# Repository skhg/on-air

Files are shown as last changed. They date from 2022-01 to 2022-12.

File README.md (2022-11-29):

# on-air

I wanted an "On Air" sign that would show up behind me while I'm in a video call at work.

Since I work from home in the living room, this is a useful indicator to my wife that I'm in a meeting (even if muted and just listening). It's also something fun that shows up behind me while in a call and gets many nice compliments!

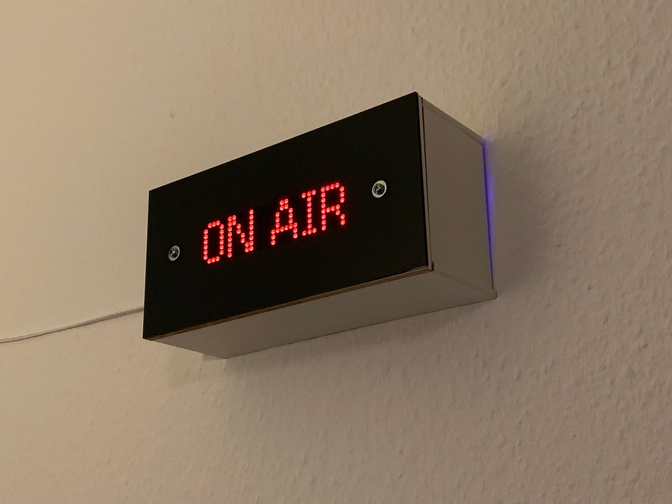
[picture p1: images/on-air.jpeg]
On air sign On Air sign


# Goals for the project
 * "On Air" status must be triggered automatically when Zoom calls begin or end
 * Learn some basic woodworking skills
 * Make the finished product look minimal and stylish
 * Learn how to use an RTC (Real-time clock) module
 * Include multiple modes so the project can be interacted with

## Materials required
Electronics:
* [NodeMCU v3 ESP8266](https://www.amazon.de/-/en/gp/product/B074Q2WM1Y/ref=ppx_yo_dt_b_search_asin_title?ie=UTF8&psc=1) microcontroller board
* 8x32 [LED matrix](https://www.amazon.de/-/en/gp/product/B079HVW652/ref=ppx_yo_dt_b_search_asin_title?ie=UTF8&psc=1)
* DS3231 [Real-time clock module](https://www.amazon.de/-/en/gp/product/B077XN4LL4/ref=ppx_yo_dt_b_search_asin_title?ie=UTF8&psc=1)
* Cables
* Breadboard
* A long [USB cable](https://www.amazon.de/-/en/gp/product/B01NCJHEHJ/ref=ppx_yo_dt_b_search_asin_title?ie=UTF8&psc=1)

Case:
* 3mm [darkened perspex / acrylic](https://www.amazon.de/-/en/gp/product/B0856148X9/ref=ppx_yo_dt_b_search_asin_title?ie=UTF8&psc=1)
* Nuts and bolts
* 6mm MDF board (sourced from leftover IKEA shelving)

Tools:
* Jigsaw
* [Clamps](https://www.amazon.de/gp/product/B0875RW1Y6/ref=ppx_yo_dt_b_asin_title_o02_s00?ie=UTF8&psc=1)
* [Wood glue](https://www.amazon.de/gp/product/B0012FBQ0U/ref=ppx_yo_dt_b_asin_title_o03_s00?ie=UTF8&psc=1)
* [Jigsaw table](https://www.amazon.de/gp/product/B0011KXNC0/ref=ppx_yo_dt_b_asin_title_o04_s00?ie=UTF8&psc=1)
* Drill

## Design, build and test
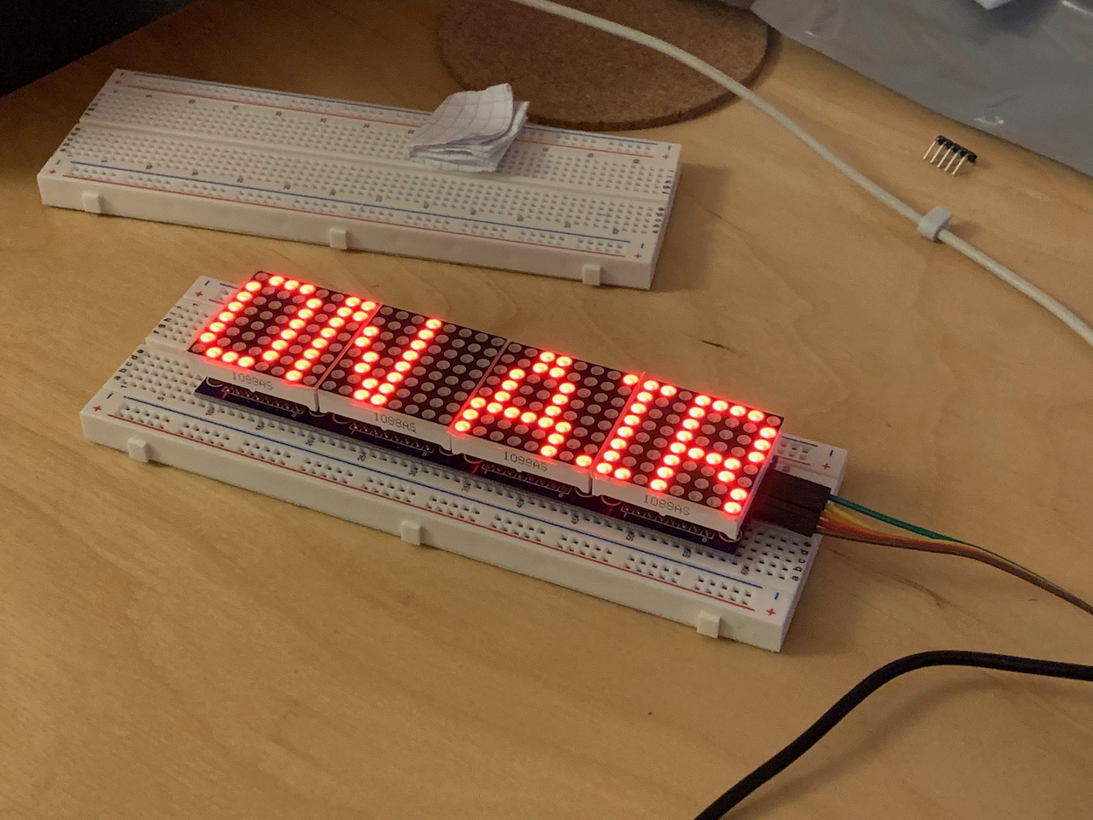
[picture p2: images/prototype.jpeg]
Prototyping the electronics came first, as usual. I hadn't worked with a large LED pixel array before, so this was the first thing I wanted to get right. With the `LedControl` library this is actually quite easy!

I was inspired by [this design](http://www.tjstephens.com/blog/2016/05/16/led-matrix-display/) which took an old wine box and converted it into an 8x64 LED display.

Beyond the cliché "ON AIR" message, I also wanted a couple of other modes to be available. As this is a wall piece that'll be visible from the whole room, a clock mode seemed obvious. That meant testing out the DS3231 RTC module. It turns out (!) that lots of DS3231 modules available online ship with a flaw that puts the battery at risk of overcharging and possible explosion. However, [desoldering a resistor](https://forum.arduino.cc/t/zs-042-ds3231-rtc-module/268862/70) will safely avoid this risk.

### Building the case
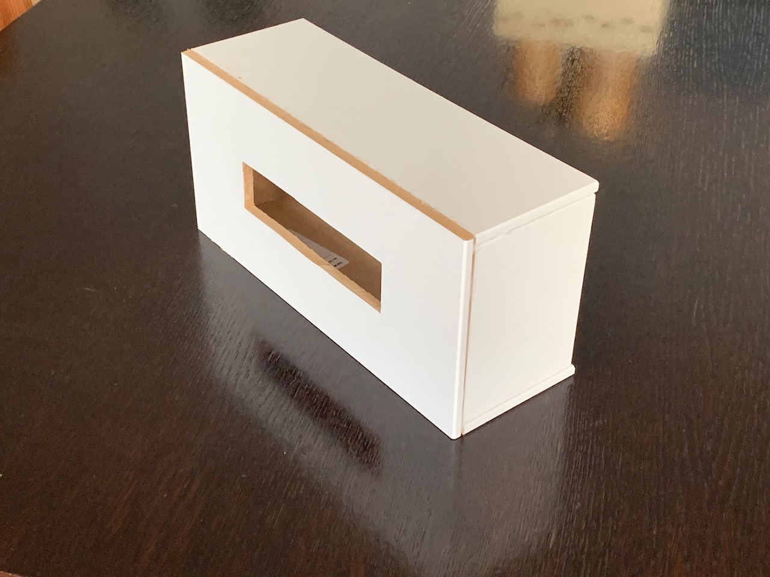
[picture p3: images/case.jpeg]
The case is made from pieces of 6mm MDF that were "upcycled" from leftover IKEA shelving. Each piece was measured and drawn out, then cut with a household jigsaw tool. Videos [like this](https://www.youtube.com/watch?v=jWneDzqAbH8) were really helpful for me to know how where to get started with it.

After cutting the pieces, and cutting out the front slot for the LED's, I applied wood glue and clamped the sides together. Some heavy weight from above helped to keep the sides stuck on to the front. I left the glue to cure for about 24 hours.

Next, I checked that the LED's fit correctly and snugly into the front slot. They did!

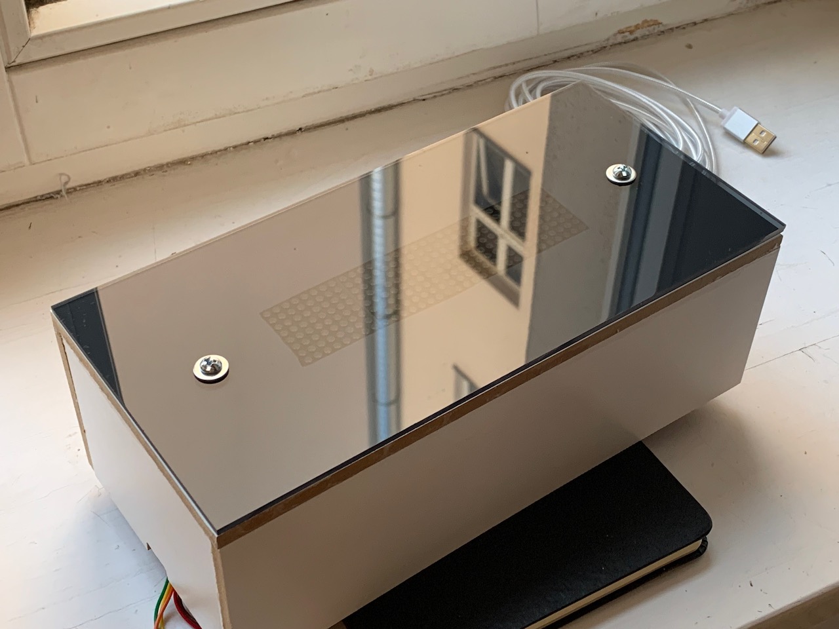
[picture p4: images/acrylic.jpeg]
The acrylic front cover came with protective plastic on both sides. Leaving this on, I carefully drilled through the acrylic to leave a clean cut on both sides. Separately I drilled through the front cover in the same location. After confirming the alignment, I removed the acrylic's protective cover and bolted it to the case, with some washers to distribute the force a little better. It's a snug fit but doesn't need to be too tight.

Final dimensions:
* 250mm wide
* 89mm deep (86mm case + 3mm acrylic)
* 120mm tall
* LED slot
  * 130mm wide
  * 32mm tall

### Circuit design

Everything is mounted on a breadboard and wired to that. There's plenty of space left inside the case - in fact it could be slimmer, if I was to build another version in the future.

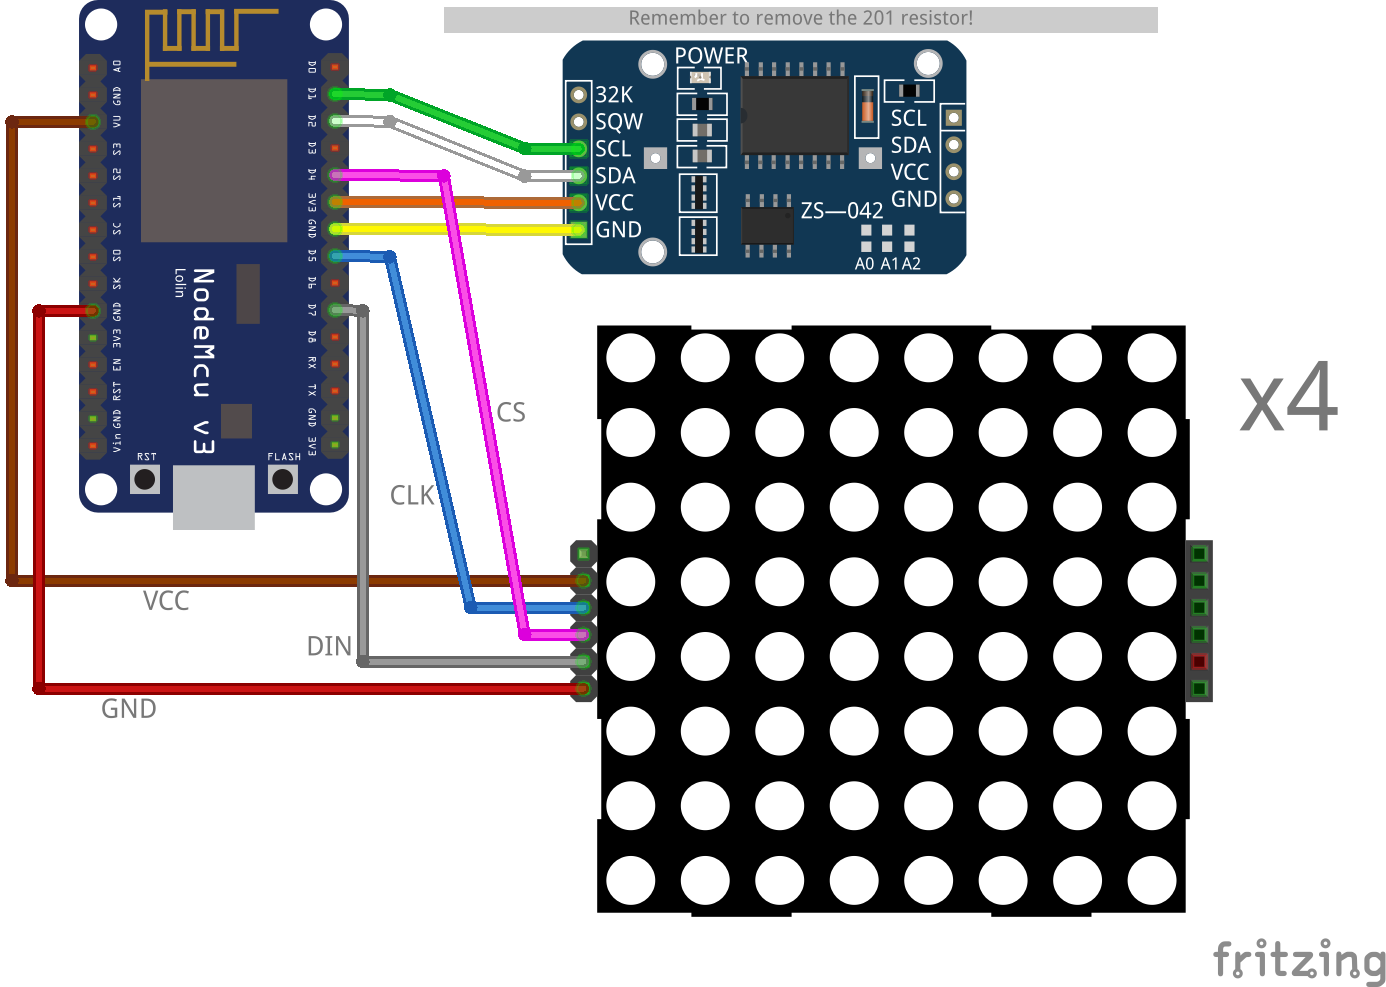
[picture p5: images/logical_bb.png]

<i>Component layout: image generated from <a href="images/logical.fzz">fritzing</a> file</i><br/><br/>

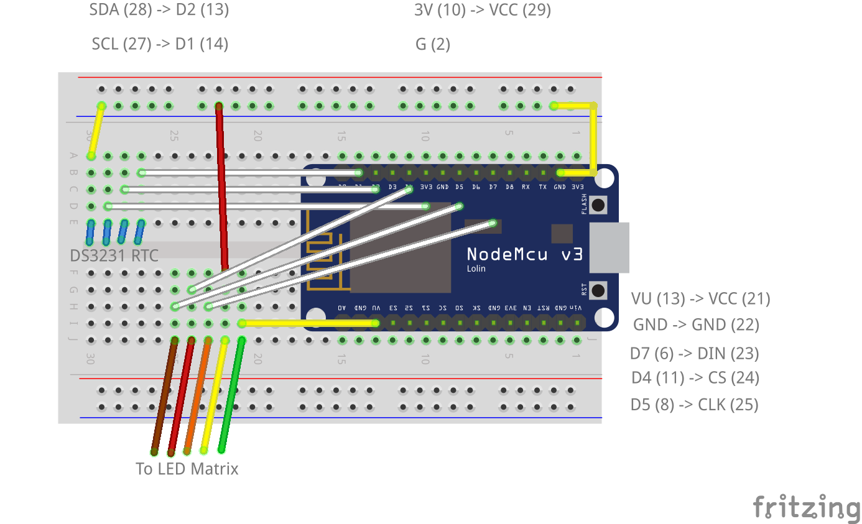
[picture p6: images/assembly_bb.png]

<i>Breadboard layout: image generated from <a href="images/assembly.fzz">fritzing</a> file</i><br/><br/>

The microcontroller board is USB powered, plugged into a wall adaptor.

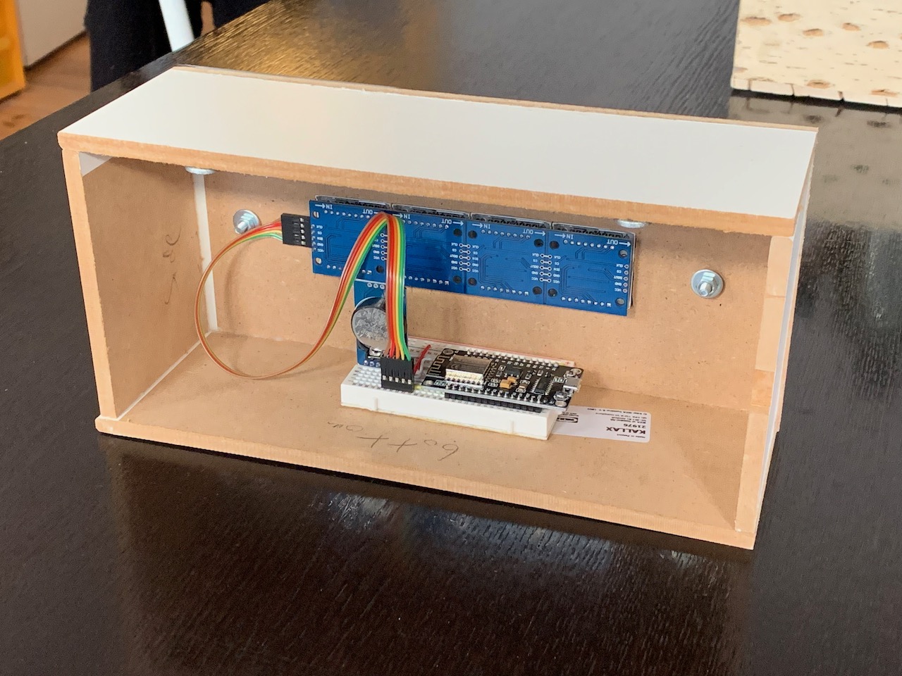
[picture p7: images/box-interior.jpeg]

<i>Breadboard and screen installed inside the box</i><br/><br/>

### Software design

The program operates on a single loop, following this workflow:

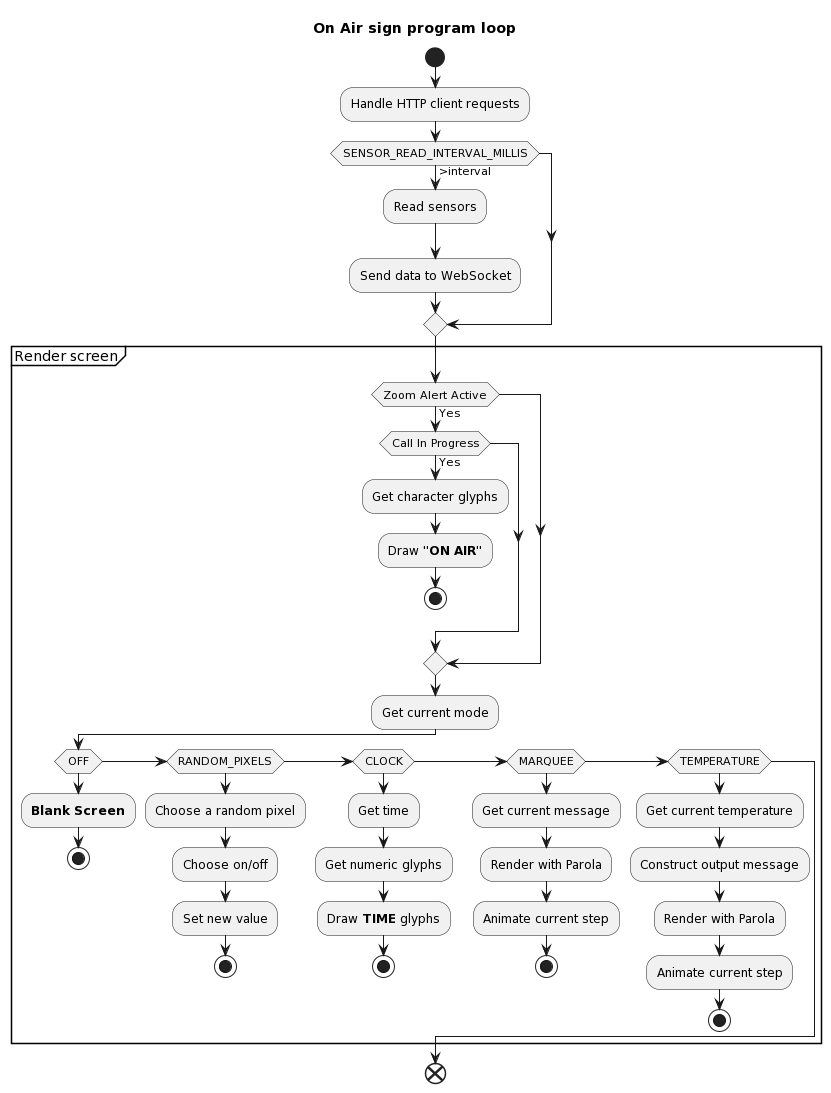
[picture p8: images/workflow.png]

<i>Generated from .puml <a href="images/workflow.puml">file</a></i><br/><br/>

### REST API
See the [Swagger docs](http://jackhiggins.ie/on-air/docs/) for details

## Remote control webapp
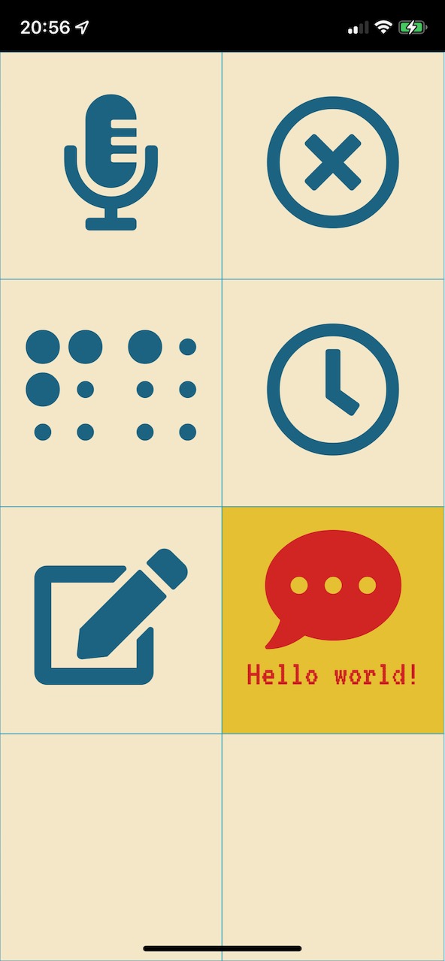
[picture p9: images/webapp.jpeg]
I based the design for the remote control application on the one I made for my [traffic light](https://github.com/skhg/traffic-light-controller/). It's pure JS/CSS with the only external dependency on [FontAwesome](https://fontawesome.com/) for icons.

It's hosted on GitHub pages so all the on-air sign has to do is proxy the initial request to load `index.html`

Updates to the sign state are shared via Websocket to all connected clients. Requests to change state are provided by the REST endpoints mentioned above.

## Zoom integration
Originally I wanted to use Zoom's webhook API to send messages to a gateway API, and then pass these on to the on-air sign. However, it turned out to be easier to use the fantastic [pyzoomproc](https://github.com/darrenpmeyer/pyzoomproc) utility, which runs on my work laptop and triggers [curl](https://github.com/curl/curl) to hit the appropriate endpoints on my sign.

## Scrolling marquee
Everyone's #1 feature request: `<marquee/>` support. From the webapp or using the `/api/message` endpoint, you can send a message that will be displayed and scroll on the screen.

Current limitations:
* Non-accented ASCII characters only
* 255 character max length

## Clock
The RTC module keeps time quite accurately, to within a few seconds over a year. I used a separate Arduino [sketch](testing/real-time-clock/real-time-clock.ino) to set the UTC time correctly once, and then I rely on the [Timezone](https://github.com/JChristensen/Timezone) library to handle local time conversions. This also conveniently handles daylight savings time adjustments.

## Temperature display
As the RTC module also includes a [thermometer](https://www.edn.com/rtc-design-part-2-temperature-compensation-is-critical/), the current temperature can also be displayed on-screen. I made a small correction because the sensor is in a closed box and doesn't get much airflow, but it seems to be fairly accurate for "room temperature" values.

## Next steps and improvements
Some future ideas:
* Include a QR code on the webapp for sharing easily

## References and helpful tools
https://www.pixilart.com/draw#

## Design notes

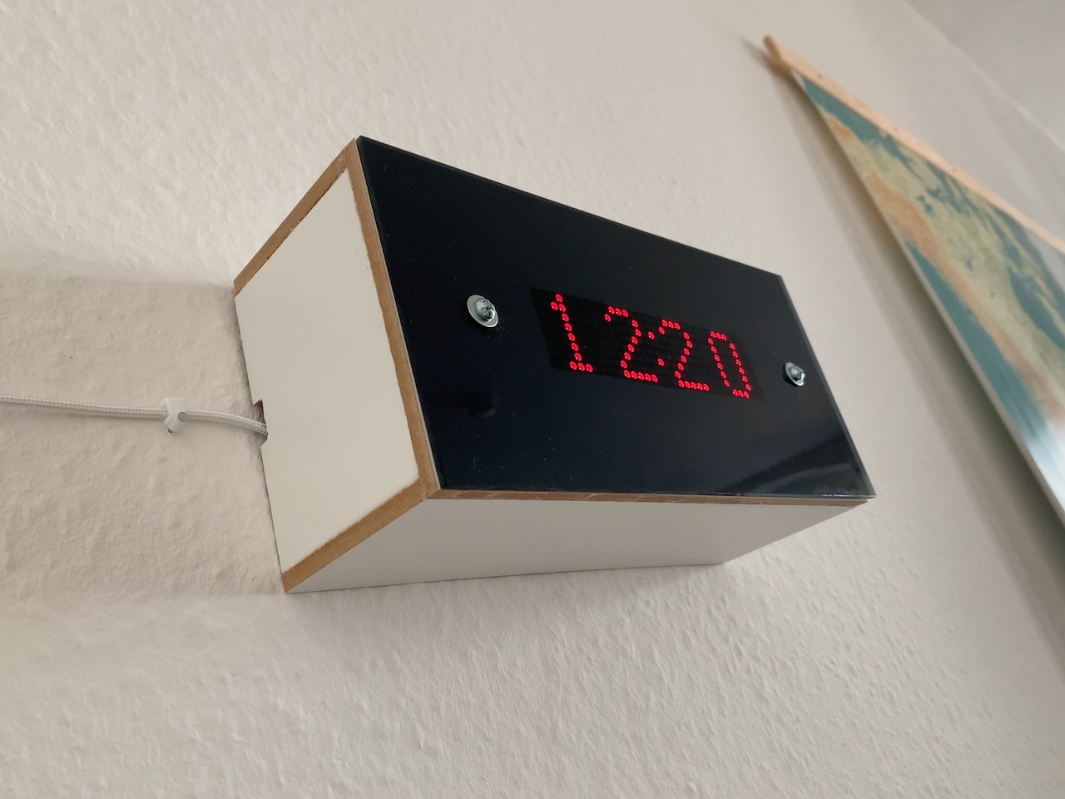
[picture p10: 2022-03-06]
images/clock.jpeg

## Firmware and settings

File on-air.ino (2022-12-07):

/**
 * Copyright 2022 Jack Higgins : https://github.com/skhg
 * All components of this project are licensed under the MIT License.
 * See the LICENSE file for details.
 */

#include <Arduino.h>
#include <ESP8266WiFi.h>
#include <WiFiClient.h>
#include <ESP8266WebServer.h>
#include <ESP8266HTTPClient.h>
#include <home_wifi.h>
#include <ArduinoJson.h>
#include <ESPAsyncTCP.h>
#include <WebSocketsServer.h>
#include <MD_MAX72xx.h>
#include <MD_Parola.h>
#include <SPI.h>
#include "./glyphs.h"
#include <DS3232RTC.h>
#include <Timezone.h>

#define LED_HARDWARE_TYPE MD_MAX72XX::FC16_HW
#define LED_COMPONENT_MODULES 4
#define LED_DIN 13  // nodemcu v3 pin D7
#define LED_CS 2  // nodemcu v3 pin D4
#define LED_CLK 14  // nodemcu v3 pin D5
#define MARQUEE_STRING_MAX_LENGTH 255

const String STATIC_CONTENT_INDEX_LOCATION =
"http://jackhiggins.ie/on-air/";

const String HOST_NAME = "on-air";

const String EMPTY_STRING = "";

const String CONTENT_TYPE_TEXT_PLAIN = "text/plain";
const String CONTENT_TYPE_APPLICATION_JSON = "application/json";
const String CONTENT_TYPE_TEXT_HTML = "text/html";

const int HTTP_OK = 200;
const int HTTP_NO_CONTENT = 204;
const int HTTP_NOT_FOUND = 404;
const int HTTP_METHOD_NOT_ALLOWED = 405;
const int HTTP_BAD_REQUEST = 400;
const int HTTP_PAYLOAD_TOO_LARGE = 413;

const String METHOD_NOT_ALLOWED_MESSAGE = "Method Not Allowed";

const float TEMPERATURE_FUDGE_FACTOR = -3.0;  // Handle slight inaccuracy in sensor
const int SENSOR_READ_INTERVAL_MILLIS = 10000;
const int RANDOM_PIXEL_INTERVAL_MILLIS = 10;
const int CLOCK_SEPARATOR_INTERVAL_MILLIS = 1000;
const int _ledBrightness = 1;  // Max 15

const textEffect_t SCROLL_EFFECT = PA_SCROLL_LEFT;
const textPosition_t SCROLL_ALIGN = PA_LEFT;
const uint16_t SCROLL_PAUSE = 0;
const uint8_t SCROLL_MS_BETWEEN_FRAMES = 50;

DS3232RTC RTC;
MD_Parola LED_DISPLAY = MD_Parola(LED_HARDWARE_TYPE, LED_CS, LED_COMPONENT_MODULES);
WiFiClient WIFI_CLIENT;
HTTPClient HTTP_CLIENT;
ESP8266WebServer HTTP_SERVER(80);
WebSocketsServer WEB_SOCKET_SERVER(81);

/**
 * Time zone configuration
 */
TimeChangeRule berlinCEST = {"CEST", Last, Sun, Mar, 2, 120};  //UTC + 2 hours
TimeChangeRule berlinCET = {"CET", Last, Sun, Oct, 3, 60};   //UTC + 1 hour
Timezone localTime(berlinCET, berlinCEST);

/**
 * States and event types
 */
enum MODES {
  OFF,
  RANDOM_PIXELS,
  CLOCK,
  MARQUEE,
  TEMPERATURE
};

float _clockTemperature = 0.0;
uint64_t _currentMillis = millis();
uint64_t _sensorReadMillis = millis();
uint64_t _randomPixelMillis = millis();

MODES _activeMode = CLOCK;
boolean _modeChanged = true;

bool _zoomAlertActive = true;
bool _zoomCallInProgress = false;

char _marqueeMessage[MARQUEE_STRING_MAX_LENGTH] = { "Hello world!" };
char _temperatureMessage[10];

/**
 * Application functions
 */

void sendToWebSocketClients(String webSocketMessage) {
  WEB_SOCKET_SERVER.broadcastTXT(webSocketMessage);
}

void readSensors() {
  _currentMillis = millis();

  if (_currentMillis - _sensorReadMillis >
        SENSOR_READ_INTERVAL_MILLIS) {
    _sensorReadMillis = _currentMillis;

    // read sensors and set the values as global vars
    _clockTemperature = (RTC.temperature() / 4.) + TEMPERATURE_FUDGE_FACTOR;

    sendToWebSocketClients(stateJson());
  }
}

void renderScreen() {
  if (_zoomAlertActive && _zoomCallInProgress) {
    renderOnAirSign();
    return;
  }

  switch (_activeMode) {
    case OFF: renderBlankScreen(); break;
    case RANDOM_PIXELS: renderRandomPixels(); break;
    case CLOCK: renderClock(); break;
    case MARQUEE: renderMarquee(); break;
    case TEMPERATURE: renderTemperature(); break;
    default: break;
  }

  _modeChanged = false;
}

void renderTemperature() {
  dtostrf(_clockTemperature, 2, 0, _temperatureMessage);
  strcat(_temperatureMessage, "\xB0""C");
  
  if (_modeChanged) {
    clearScreen();
    LED_DISPLAY.displayText(_temperatureMessage, PA_CENTER, SCROLL_MS_BETWEEN_FRAMES, SCROLL_PAUSE, PA_NO_EFFECT, PA_NO_EFFECT);
  }

  if (LED_DISPLAY.displayAnimate()) {
    LED_DISPLAY.displayReset();
  }
}

void renderMarquee() {
  if (_modeChanged) {
    clearScreen();
    LED_DISPLAY.displayText(_marqueeMessage, SCROLL_ALIGN, SCROLL_MS_BETWEEN_FRAMES, SCROLL_PAUSE, SCROLL_EFFECT, SCROLL_EFFECT);
  }

  if (LED_DISPLAY.displayAnimate()) {
    LED_DISPLAY.displayReset();
  }
}

void renderClock() {
  time_t utc = now();
  time_t local = localTime.toLocal(utc);
  
  int currentHour = hour(local);
  int currentMinute = minute(local);
  int currentSecond = second(local);

  int digit1 = currentHour / 10;
  int digit2 = currentHour % 10;

  int digit3 = currentMinute / 10;
  int digit4 = currentMinute % 10;

  print8x8(3, getGlyphForInteger(digit1));
  print8x8(2, getGlyphForInteger(digit2), currentSecond % 2 == 0 ? GLYPH_CLOCK_SEPARATOR : GLYPH_EMPTY);
  print8x8(1, getGlyphForInteger(digit3));
  print8x8(0, getGlyphForInteger(digit4));
}

void renderBlankScreen() {
  clearScreen();
}

void renderOnAirSign() {
  print8x8(3, GLYPH_ON_AIR_BLOCK_0);
  print8x8(2, GLYPH_ON_AIR_BLOCK_1);
  print8x8(1, GLYPH_ON_AIR_BLOCK_2);
  print8x8(0, GLYPH_ON_AIR_BLOCK_3);
}

void renderRandomPixels() {
  _currentMillis = millis();

  if (_currentMillis - _randomPixelMillis <= RANDOM_PIXEL_INTERVAL_MILLIS) {
    return;
  }

  _randomPixelMillis = _currentMillis;

  int row = random(8);
  int column = random(8 * LED_COMPONENT_MODULES);
  int state = random(2);

  LED_DISPLAY.getGraphicObject()->setPoint(row, column, state);
}

void print8x8(int screenId, const byte pixels1[]) {
  print8x8(screenId, pixels1, GLYPH_EMPTY);
}

void print8x8(int screenId, const byte pixels1[], const byte pixels2[]) {
  for (int i = 0; i < 8; i++) {
    byte combo = B00000000;

    for (int j=0; j < 8; j++) {
      boolean outcome = bitRead(pixels1[i], j) || bitRead(pixels2[i], j);
      bitWrite(combo, j, outcome);
    }

    LED_DISPLAY.getGraphicObject()->setRow(screenId, screenId, i, combo);
  }
}

void httpRootEventHandler() {
  if (HTTP_SERVER.method() != HTTP_GET) {
    HTTP_SERVER.send(HTTP_METHOD_NOT_ALLOWED, CONTENT_TYPE_TEXT_PLAIN,
      METHOD_NOT_ALLOWED_MESSAGE);
    return;
  }

  // Fetch content from source and forward it
  HTTP_CLIENT.begin(WIFI_CLIENT, STATIC_CONTENT_INDEX_LOCATION);
  HTTP_CLIENT.GET();

  HTTP_SERVER.sendHeader("Cache-Control", "no-cache");
  HTTP_SERVER.send(HTTP_OK, "text/html", HTTP_CLIENT.getString());
}

void httpNotFoundEventHandler() {
  String message = "File Not Found\n\n";
  message += "URI: ";
  message += HTTP_SERVER.uri();
  message += "\nMethod: ";
  message += (HTTP_SERVER.method() == HTTP_GET) ? "GET" : "POST";
  message += "\nArguments: ";
  message += HTTP_SERVER.args();
  message += "\n";
  for (uint8_t i = 0; i < HTTP_SERVER.args(); i++) {
    message += " " + HTTP_SERVER.argName(i) + ": " + HTTP_SERVER.arg(i) + "\n";
  }
  HTTP_SERVER.send(HTTP_NOT_FOUND, CONTENT_TYPE_TEXT_PLAIN, message);
}

void statusHttpEventHandler() {
  if (HTTP_SERVER.method() != HTTP_GET) {
    HTTP_SERVER.send(HTTP_METHOD_NOT_ALLOWED, CONTENT_TYPE_TEXT_PLAIN,
      METHOD_NOT_ALLOWED_MESSAGE);
  } else {
    HTTP_SERVER.send(HTTP_OK, CONTENT_TYPE_APPLICATION_JSON, stateJson());
  }
}

String stateJson() {
  String jsonContent;

  StaticJsonDocument<512> statusJson;
  statusJson["mode"] = modeToString(_activeMode);
  statusJson["message"] = _marqueeMessage;
  statusJson["temperature"] = _clockTemperature;

  JsonObject zoomJson = statusJson.createNestedObject("zoom");
  zoomJson["alert-active"] = _zoomAlertActive;
  zoomJson["call-in-progress"] = _zoomCallInProgress;

  serializeJson(statusJson, jsonContent);

  return jsonContent;
}

void messageHttpEventHandler() {
  if (HTTP_SERVER.method() == HTTP_PUT) {
    if (HTTP_SERVER.hasArg("plain") == false) {
      HTTP_SERVER.send(HTTP_BAD_REQUEST, CONTENT_TYPE_TEXT_PLAIN,
        "Missing body");
    } else {
      StaticJsonDocument<512> newMessageJson;
      DeserializationError err = deserializeJson(newMessageJson, HTTP_SERVER.arg("plain"));

      if (err) {
        Serial.println("Deserialising new message failed!");
        Serial.println(err.c_str());
        HTTP_SERVER.send(HTTP_BAD_REQUEST, CONTENT_TYPE_TEXT_PLAIN,
        "Invalid message");
        return;
      }

      String possibleNewMessage = newMessageJson["value"];
      if (possibleNewMessage.length() > MARQUEE_STRING_MAX_LENGTH) {
        HTTP_SERVER.send(HTTP_PAYLOAD_TOO_LARGE, CONTENT_TYPE_TEXT_PLAIN,
        "Message too long. Must be 255 characters or less.");
        return;
      }

      strcpy(_marqueeMessage, newMessageJson["value"]);

      _modeChanged = true;
      HTTP_SERVER.send(HTTP_NO_CONTENT, CONTENT_TYPE_TEXT_PLAIN, EMPTY_STRING);
      sendToWebSocketClients(stateJson());
    }
  } else if (HTTP_SERVER.method() == HTTP_DELETE) {
    _activeMode = OFF;
    HTTP_SERVER.send(HTTP_NO_CONTENT, CONTENT_TYPE_TEXT_PLAIN, EMPTY_STRING);
    sendToWebSocketClients(stateJson());
  } else {
    HTTP_SERVER.send(HTTP_METHOD_NOT_ALLOWED, CONTENT_TYPE_TEXT_PLAIN,
      METHOD_NOT_ALLOWED_MESSAGE);
  }
}

void modeHttpEventHandler() {
  if (HTTP_SERVER.method() == HTTP_PUT) {
    if (HTTP_SERVER.hasArg("plain") == false) {
      HTTP_SERVER.send(HTTP_BAD_REQUEST, CONTENT_TYPE_TEXT_PLAIN,
        "Missing body");
    } else {
      StaticJsonDocument<48> newModeJson;
      DeserializationError err = deserializeJson(newModeJson, HTTP_SERVER.arg("plain"));

      if (err) {
        Serial.println("Deserialising new mode failed!");
        Serial.println(err.c_str());
        HTTP_SERVER.send(HTTP_BAD_REQUEST, CONTENT_TYPE_TEXT_PLAIN,
        "Invalid mode");
        return;
      }

      MODES newMode = stringToMode(newModeJson["name"]);
      if (newMode != _activeMode) {
        _activeMode = newMode;
        _modeChanged = true;
        sendToWebSocketClients(stateJson());
      }
      
      HTTP_SERVER.send(HTTP_NO_CONTENT, CONTENT_TYPE_TEXT_PLAIN, EMPTY_STRING);
    }
  } else if (HTTP_SERVER.method() == HTTP_DELETE) {
    _activeMode = OFF;
    HTTP_SERVER.send(HTTP_NO_CONTENT, CONTENT_TYPE_TEXT_PLAIN, EMPTY_STRING);
    sendToWebSocketClients(stateJson());
  } else {
    HTTP_SERVER.send(HTTP_METHOD_NOT_ALLOWED, CONTENT_TYPE_TEXT_PLAIN,
      METHOD_NOT_ALLOWED_MESSAGE);
  }
}

MODES stringToMode(String mode) {
  if (mode == "random-pixels") {
    return RANDOM_PIXELS;
  } else if (mode == "clock") {
    return CLOCK;
  } else if (mode == "marquee") {
    return MARQUEE;
  } else if (mode == "temperature") {
    return TEMPERATURE;
  } else {
    return OFF;
  }
}

String modeToString(MODES mode) {
  switch (mode) {
    case OFF: return "off";
    case RANDOM_PIXELS: return "random-pixels";
    case CLOCK: return "clock";
    case MARQUEE: return "marquee";
    case TEMPERATURE: return "temperature";
    default: return "Unknown";
  }
}

void zoomAlertHttpEventHandler() {
  if (HTTP_SERVER.method() == HTTP_PUT) {
    _zoomAlertActive = true;
    HTTP_SERVER.send(HTTP_NO_CONTENT, CONTENT_TYPE_TEXT_PLAIN, EMPTY_STRING);
    sendToWebSocketClients(stateJson());
  } else if (HTTP_SERVER.method() == HTTP_DELETE) {
    _zoomAlertActive = false;
    HTTP_SERVER.send(HTTP_NO_CONTENT, CONTENT_TYPE_TEXT_PLAIN, EMPTY_STRING);
    sendToWebSocketClients(stateJson());
  } else {
    HTTP_SERVER.send(HTTP_METHOD_NOT_ALLOWED, CONTENT_TYPE_TEXT_PLAIN,
      METHOD_NOT_ALLOWED_MESSAGE);
  }
}

void zoomCallHttpEventHandler() {
  if (HTTP_SERVER.method() == HTTP_PUT) {
    _zoomCallInProgress = true;
    HTTP_SERVER.send(HTTP_NO_CONTENT, CONTENT_TYPE_TEXT_PLAIN, EMPTY_STRING);
    sendToWebSocketClients(stateJson());
  } else if (HTTP_SERVER.method() == HTTP_DELETE) {
    _zoomCallInProgress = false;
    HTTP_SERVER.send(HTTP_NO_CONTENT, CONTENT_TYPE_TEXT_PLAIN, EMPTY_STRING);
    sendToWebSocketClients(stateJson());
  } else {
    HTTP_SERVER.send(HTTP_METHOD_NOT_ALLOWED, CONTENT_TYPE_TEXT_PLAIN,
      METHOD_NOT_ALLOWED_MESSAGE);
  }
}

void webSocketEventHandler(uint8_t num, WStype_t type, uint8_t * payload,
  size_t length) {
  IPAddress ip = WEB_SOCKET_SERVER.remoteIP(num);

  switch (type) {
    case WStype_DISCONNECTED: {
      Serial.println("WebSocket client disconnected.");
      break;
    }
    case WStype_CONNECTED: {
      Serial.print("WebSocket client at ");
      Serial.print(ip);
      Serial.println(" connected.");
      break;
    }
  }
}

void clearScreen() {
  LED_DISPLAY.setIntensity(_ledBrightness);
  LED_DISPLAY.displayClear();
}

/**
 * Essential system functions
 */

void setup(void) {
  randomSeed(analogRead(0));
  Serial.begin(115200);

  RTC.begin();
  setSyncProvider(RTC.get);

  LED_DISPLAY.begin();
  clearScreen();

  WiFi.begin(WIFI_SSID, WIFI_PASSWORD);
  WiFi.hostname(HOST_NAME);

  Serial.println(EMPTY_STRING);

  // Wait for connection
  while (WiFi.status() != WL_CONNECTED) {
    delay(500);
    Serial.print(".");
  }
  Serial.println(EMPTY_STRING);
  Serial.print("Connected to ");
  Serial.println(WIFI_SSID);
  Serial.print("Access at http://");
  Serial.print(WiFi.localIP());
  Serial.print("/ or http://");
  Serial.print(HOST_NAME);
  Serial.println("/");

  HTTP_SERVER.on("/", httpRootEventHandler);
  HTTP_SERVER.on("/api/status", statusHttpEventHandler);
  HTTP_SERVER.on("/api/mode", modeHttpEventHandler);
  HTTP_SERVER.on("/api/message", messageHttpEventHandler);
  HTTP_SERVER.on("/api/alert/zoom", zoomAlertHttpEventHandler);
  HTTP_SERVER.on("/api/alert/zoom/call", zoomCallHttpEventHandler);

  HTTP_SERVER.onNotFound(httpNotFoundEventHandler);

  HTTP_SERVER.begin();
  Serial.println("HTTP server started");

  WEB_SOCKET_SERVER.begin();

  // Disconnect after a single failed heartbeat
  WEB_SOCKET_SERVER.enableHeartbeat(1000, 1000, 1);
  WEB_SOCKET_SERVER.onEvent(webSocketEventHandler);
}

void loop(void) {
  HTTP_SERVER.handleClient();
  readSensors();
  renderScreen();
}

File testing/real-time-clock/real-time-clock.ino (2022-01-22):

/**
 * Arduino DS3232RTC Library
 * https://github.com/JChristensen/DS3232RTC
 * Copyright (C) 2018 by Jack Christensen and licensed under
 * GNU GPL v3.0, https://www.gnu.org/licenses/gpl.html
 */

#include <DS3232RTC.h>

DS3232RTC RTC;

/**
 * Copied from https://github.com/JChristensen/DS3232RTC/blob/master/examples/SetSerial/SetSerial.ino
 * Physical modifications including removing the 201 resistor instructions from https://forum.arduino.cc/t/zs-042-ds3231-rtc-module/268862/70
 * 
 * Example sketch to display the date and time from a DS3231
 * or DS3232 RTC every second. Display the temperature once per
 * minute. (The DS3231 does a temperature conversion once every
 * 64 seconds. This is also the default for the DS3232.)
 * 
 * Set the date and time by entering the following on the Arduino
 * serial monitor:
 * year,month,day,hour,minute,second,
 * 
 * Where
 * year can be two or four digits,
 * month is 1-12,
 * day is 1-31,
 * hour is 0-23, and
 * minute and second are 0-59.
 * 
 * Entering the final comma delimiter (after "second") will avoid a
 * one-second timeout and will allow the RTC to be set more accurately.
 * 
 * No validity checking is done, invalid values or incomplete syntax
 * in the input will result in an incorrect RTC setting.
 * 
 * Jack Christensen 08Aug2013
 */

#include <Streaming.h>      // http://arduiniana.org/libraries/streaming/

void setup() {
    Serial.begin(115200);

    // setSyncProvider() causes the Time library to synchronize with the
    // external RTC by calling RTC.get() every five minutes by default.
    setSyncProvider(RTC.get);
    Serial << F("RTC Sync");
    if (timeStatus() != timeSet) Serial << F(" FAIL!");
    Serial << endl;
}

void loop() {
    static time_t tLast;
    time_t t;
    tmElements_t tm;

    // check for input to set the RTC, minimum length is 12, i.e. yy,m,d,h,m,s
    if (Serial.available() >= 12) {
        // note that the tmElements_t Year member is an offset from 1970,
        // but the RTC wants the last two digits of the calendar year.
        // use convenience macros from the Time Library to do the conversions.
        int y = Serial.parseInt();
        if (y >= 100 && y < 1000) {
            Serial << F("Error: Year must be two or four digits!") << endl;
        } else {
            if (y >= 1000) {
                tm.Year = CalendarYrToTm(y);
            } else {    // (y < 100)
                tm.Year = y2kYearToTm(y);
            }
            tm.Month = Serial.parseInt();
            tm.Day = Serial.parseInt();
            tm.Hour = Serial.parseInt();
            tm.Minute = Serial.parseInt();
            tm.Second = Serial.parseInt();
            t = makeTime(tm);
            RTC.set(t);  // use time_t value to ensure correct weekday is set
            setTime(t);
            Serial << F("RTC set to: ");
            printDateTime(t);
            Serial << endl;
            // dump any extraneous input
            while (Serial.available() > 0) Serial.read();
        }
    }

    t = now();
    if (t != tLast) {
        tLast = t;
        printDateTime(t);
        if (second(t) == 0) {
            float c = RTC.temperature() / 4.;
            float f = c * 9. / 5. + 32.;
            Serial << F("  ") << c << F(" C  ") << f << F(" F");
        }
        Serial << endl;
    }
}

// print date and time to Serial
void printDateTime(time_t t) {
    printDate(t);
    Serial << ' ';
    printTime(t);
}

// print time to Serial
void printTime(time_t t) {
    printI00(hour(t), ':');
    printI00(minute(t), ':');
    printI00(second(t), ' ');
}

// print date to Serial
void printDate(time_t t) {
    printI00(day(t), 0);
    Serial << monthShortStr(month(t)) << _DEC(year(t));
}

// Print an integer in "00" format (with leading zero),
// followed by a delimiter character to Serial.
// Input value assumed to be between 0 and 99.
void printI00(int val, char delim) {
    if (val < 10) Serial << '0';
    Serial << _DEC(val);
    if (delim > 0) Serial << delim;
    return;
}

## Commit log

2022-01-21 Initial checkin (#1)
    * testing basic function of led matrix
    * github action
    * gitignore
    * linted
    * comment out stuff for later
    * remove for later
    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
    [led-matrix.fzz]
2022-01-22 Real Time Clock testing (#2)
    * rtc learning
    * after desoldering the 201 resistor
    * add missing compile dependency
    * add missing compile dependency
    [real-time-clock.fzz]
2022-01-30 Webapp (#5)
    * http endpoints to handle zoom events and simplify stuff
    * linting
    * webapp
    * working with the webapp
    * basic grid outline with minimal js and css
    * re-add js linting stuff
    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
2022-02-11 Add a clock mode! (#10)
    * basic clock function
    * handle request to set clock mode and make it non-defaul
    * render clock
    * remove unnecessary import
    * clock control from webapp
    * report temperature state
    * fix linting and rename pixels to glyphs
    * change pipeline order
    * cpplint
    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
    [on-air.ino]
2022-03-06 Nicer docs (#13)
    * worked on readme
    * worked on readme
    * worked on readme
    * images
    * size
    * add diagram and readme
    * br
    * add swagger stuff to docs
    * correct path to yml
    * openapi spec basic stuff
    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
    [assembly.fzz, logical.fzz]
2022-03-07 Additional docs (#14)
    * box photo
    * layout
    * diagram
    * program workflow
    * workflow
    * swagger docs
    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
    [assembly.fzz]
2022-03-27 Add scrolling text mode (#15)
    * switch graphics library to MD_MAX72xx
    * tidy
    * more functionality and tidy up
    * rename
    * control text from webapp
    * required libs
    * remove the pause
    * tidy up
    * add webapp stuff for scrolling, and handle deserialisation errors in arduino code
    * tidy up
    * element positioning for frontend
    * change regex rule because i want to remove these chars
    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
    [on-air.ino]
2022-11-29 Add temperature display feature (#20)
    * add temperature display feature
    * webapp changes to support temperature mode
    * udpate workflow digram
    * mention temperature in readme
